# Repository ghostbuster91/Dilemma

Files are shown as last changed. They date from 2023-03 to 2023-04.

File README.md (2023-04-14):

This is a modified version of Dilemma keyboard 3x6_3 with more aggerssive pinky stagger.

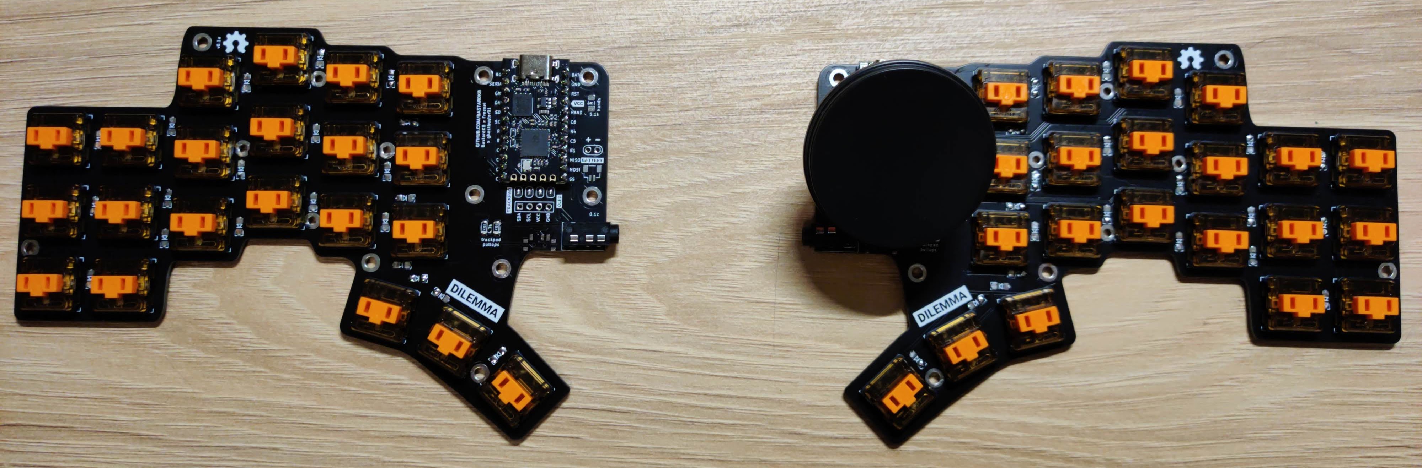
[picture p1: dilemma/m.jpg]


Head over [here](./dilemma/build_guide.md) for a build guide.

QMK firmaware: https://github.com/ghostbuster91/qmk_firmware/tree/bkb-master/keyboards/bastardkb/dilemma/3x6_3

<div align="center">




</div>

---

The Dilemma is a vertical stagger low-profile keyboard with mods.



## Table of contents

- [Features](#features)
- [Versions](#versions)
- [Wireless abilities](#wireless-abilities)
- [BOM](#bom)
  - [DIY version](#diy-version)
  - [Assembled version](#assembled-version)
  - [Trackpad mod](#trackpad-mod)
  - [Cases](#cases)
- [Community mods](#community-mods)
- [Build guide](#build-guide)
- [Forks](#forks)
- [Support me on patreon](#support-me-on-patreon)
- [Others / in progress](#others--in-progress)

---

## Features

- Heavy pinky stagger
- MX and choc compatible
- Reversible PCB
- Elite-pi / Splinky / Nice!Nano compatible
- Tenting puck footprint

## Versions

There are 2 versions of the dilemma, in 2 folders:

- `dilemma`, for DIY that requires an additional MCU (eg. kb2040)
- `dilemma_assembled`, for PCB assembly

The Dilemma is **made for rp2040**, so if you go with the DIY version you should source your MCU board accordingly.

## Wireless abilities

ZMK does not support input devices at the moment, and QMK does not support BLE.

However, as this is meant to be a portable keyboard, some ground work has been laid with the DIY version:

- pinout compatible with nice!nano
- 2 battery connectors footprints: JST, and THT
- on / off button footprint

At this time, the assembled version does not support wireless.

## BOM

The PCB can work on standalone.

Depending on which version you go with, you will need to source different items.

On top of the basic build, you can add a range of options, which require additional components:

- 3d printed case
- mods (eg. trackpad)

Both versions of the Dilemma require:

| Part name | Amount | Link / source |
| --- | --- | --- |
| Audio jack | 2 | |
| Button, 4x4x1.5 | 2 | |

### DIY version

On top of the parts mentioned above, you will need:

| Part name | Amount | Link / source |
| --- | --- | --- |
| SOD123 Diodes | 34 | Farnell, Mouser, Aliexpress |
| Dilemma PCB, DIY, 1.2mm | 2 | See Release section |
| RP2040 MCU board | 2 | KB2040, elite-pi... |
| Header pins | 2\*12  | |

Please note, **the Dilemma is compatible only with rp2040 boards !**

The release section contains the latest gerbers.

Order in 1.2mm thickness.

### Assembled version



On top of the parts mentioned above, you will need:

| Part name | Amount | Link / source |
| --- | --- | --- |
| Dilemma PCB, assembled, 1.2mm | 2 | See Release section |

The release section contains the latest gerbers with BOM and POS files.

Order in 1.2mm thickness.

### Trackpad mod



This is the first mod made for the keyboard - so it can function as a standalone input device.

It uses I2C on the DIY version, and SPI on the assembled version.

The DIY version requires removing 2 resistors from the trackpad (see build guide).

When installing the trackpad mod, you will need:

| Part name | Amount | Link / source |
| --- | --- | --- |
| M3 screw, torx, 6mm | 4 | Conrad |
| M3x5x5 screw insert | 4 | Aliexpress |
| Cirque trackpad\* | 1 | Mouser |
| 3d printed parts\*  | | See `mechanical` folder |

\*You can use either the 35mm (TM035035-2024-003) or 40mm (TM040040-2024-303).
Print the appropriate parts from the `mechanical` folder.

If building the PCBA version, you will also need:

| Part name | Amount | Link / source |
| --- | --- | --- |
| 12-position FPC cable, 0.5mm pitch, same side contacts, 100mm | 1 | Farnell |

If building the DIY version, you will also need:

| Part name | Amount | Link / source |
| --- | --- | --- |
| SOD123 Resistor, 5kOhms | 2 | |
| Cables | | |

### Cases

There are a range of cases available. See details in the `mechanical/cases` folder.



## Community mods

There are a range of community mods available (hex plates, covers...).

You can find more information in the readme in the `mechanical/community mods` folder.



## Build guide

https://docs.bastardkb.com/hc/en-us/sections/6848232395410-Dilemma

## Forks

- [3x6 version](https://github.com/bstiq/Dilemma_3x6/)
- [3x5 + 3 version](https://github.com/dixls/Dilemma-3mod)

## Support me on Patreon

If you like the keyboard, please consider helping me with Patreon: https://www.patreon.com/bastardkb

I post regular updates and hindsight on my work. I work full time on keyboard innovation, and this helps a lot !

## Others / in progress

The PCB has available connectors for:

- oled

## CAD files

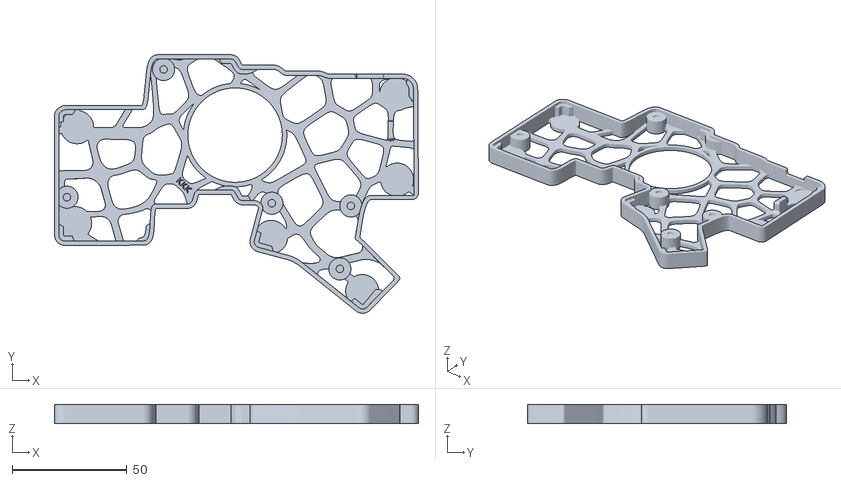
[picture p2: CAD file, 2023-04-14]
mechanical/cases/tenting_puck/tenting_puck_v3_26_mod.stl
158.9 x 112.9 x 8.40

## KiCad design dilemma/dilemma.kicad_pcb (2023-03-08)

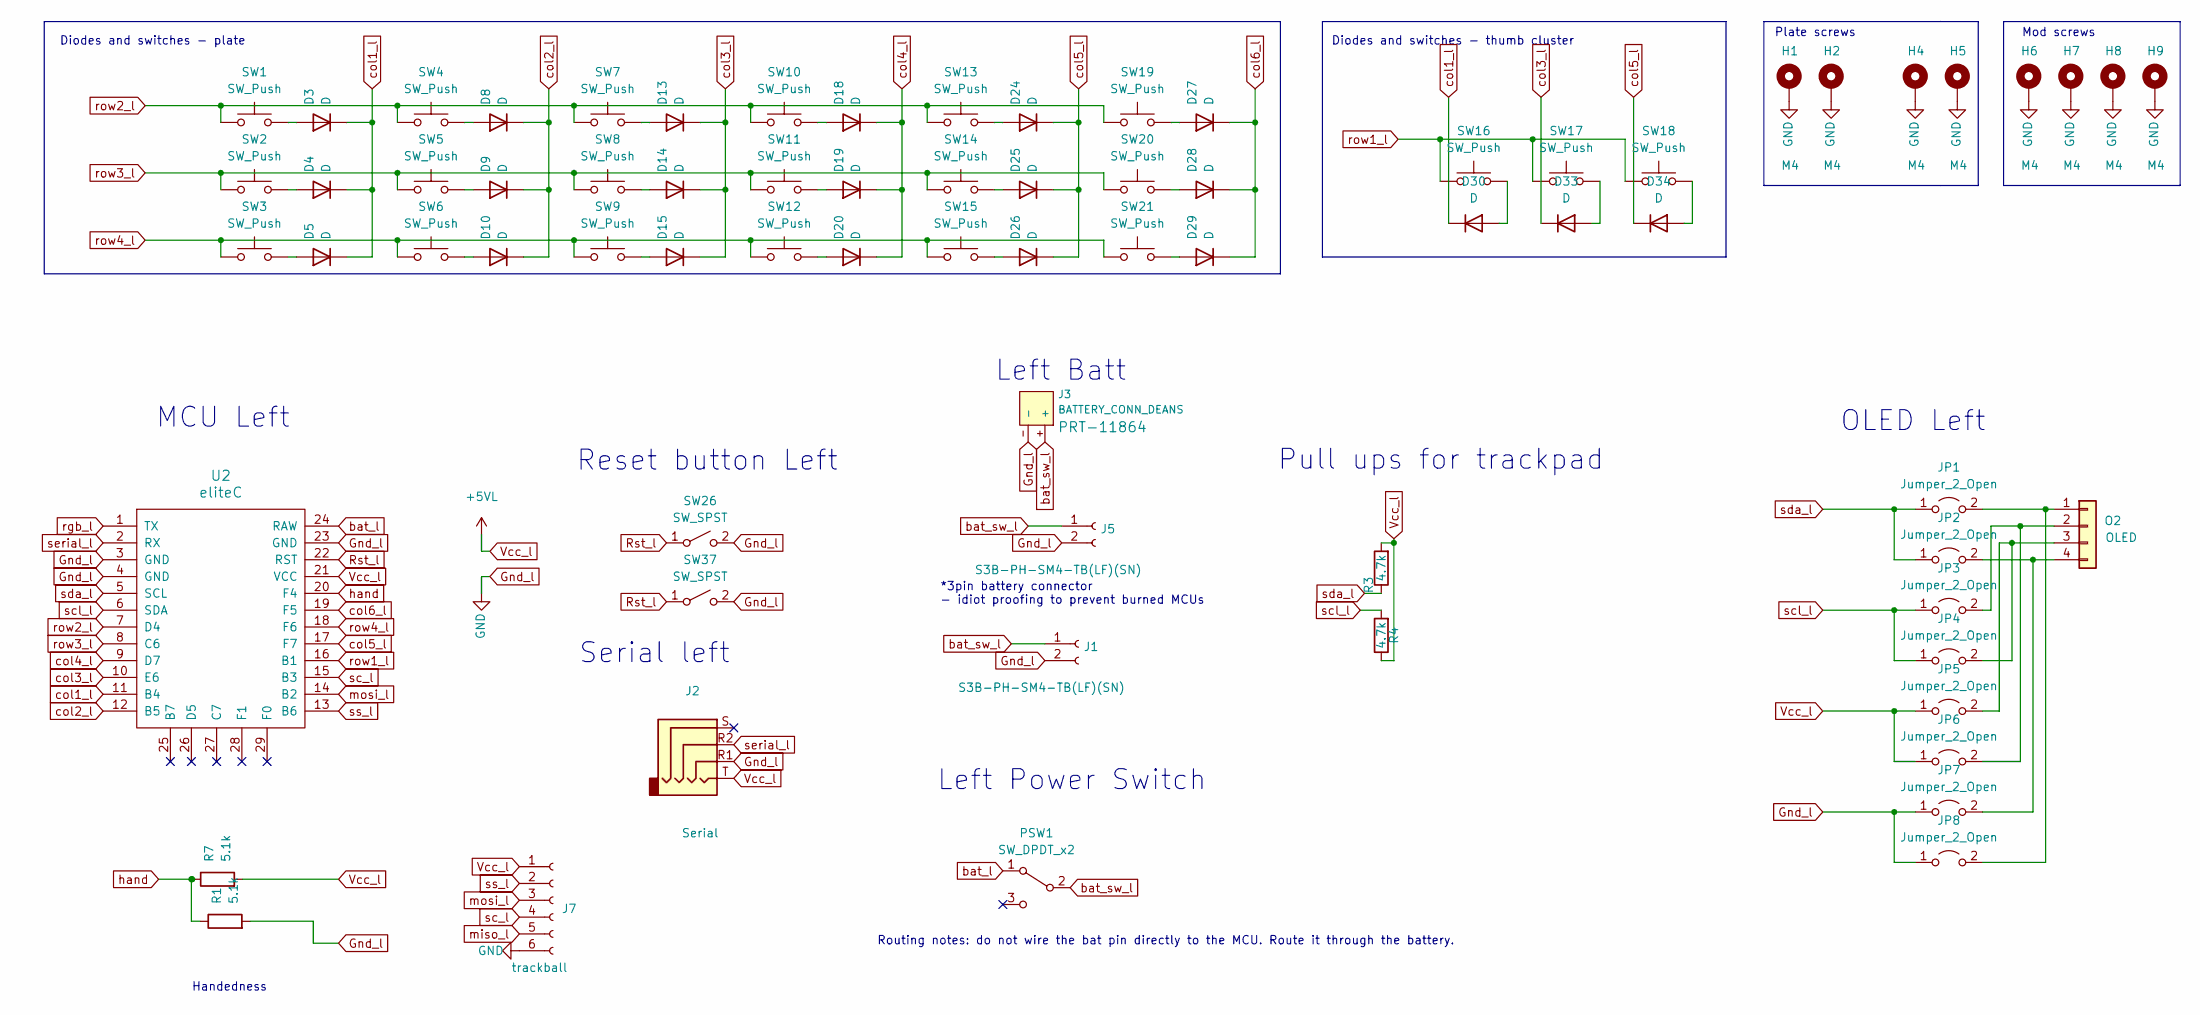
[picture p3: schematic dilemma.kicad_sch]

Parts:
D3, D4, D5, D8, D9, D10, D13, D14, D15, D18, D19, D20, D24, D25, D26, D27, D28, D29, D30, D33, D34: D; D_1206_handsolder_reversible
H1, H2, H4, H5, H6, H7, H8, H9: M4; MountingHole_3mm_Pad_thin
J1, J5: S3B-PH-SM4-TB(LF)(SN); JST_SH_BM02B-SRSS-TB_1x02-1MP_P1.00mm_Vertical; LCSC C265101
J2: Serial; Jack_3.5mm_PJ320E_Horizontal_reversible
J3: BATTERY_CONN_DEANS; battery_connector_THT
J7: trackball; 6_PinHeader
JP1, JP2, JP3, JP4, JP5, JP6, JP7, JP8: Jumper_2_Open; SolderJumper-2_P1.3mm_Open_RoundedPad1.0x1.5mm
O2: OLED; PinHeader_1x04_P2.54mm_Vertical
PSW1: SW_DPDT_x2; Switch_MSK-12C01-07; LCSC C431540
R1, R7: 5.1k; R_1206_handsolder; JLCPCB BOM 1
R3, R4: 4.7k; R_1206_handsolder_reversible; LCSC C269746
SW1, SW2, SW3, SW4, SW5, SW6, SW7, SW8, SW9, SW10, SW11, SW12, SW13, SW14, SW15, SW16, SW17, SW18, SW19, SW20, SW21: SW_Push; SW_MX_choc
SW26, SW37: SW_SPST; SW_Push_1P1T_NO_6x6mm_H9.5mm
U2: eliteC; pro-micro

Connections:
Gnd_l: H1.1, H2.1, H4.1, H5.1, H6.1, H7.1, H8.1, H9.1, J1.2, J2.R1, J3.-, J5.2, J7.6, JP7.1 (A), JP8.1 (A), R1.2, SW26.2 (B), SW37.2 (B), U2.3 (GND), U2.4 (GND), U2.23 (GND)
unnamed: D3.2 (A), SW1.2
unnamed: D4.2 (A), SW2.2
unnamed: D5.2 (A), SW3.2
unnamed: D8.2 (A), SW4.2
unnamed: D9.2 (A), SW5.2
unnamed: D10.2 (A), SW6.2
unnamed: D13.2 (A), SW7.2
unnamed: D14.2 (A), SW8.2
unnamed: D15.2 (A), SW9.2
unnamed: D18.2 (A), SW10.2
unnamed: D19.2 (A), SW11.2
unnamed: D20.2 (A), SW12.2
unnamed: D24.2 (A), SW13.2
unnamed: D25.2 (A), SW14.2
unnamed: D26.2 (A), SW15.2
unnamed: D30.2 (A), SW16.2
unnamed: D33.2 (A), SW17.2
unnamed: D34.2 (A), SW18.2
unnamed: JP1.2 (B), JP8.2 (B), O2.1
unnamed: JP2.2 (B), JP7.2 (B), O2.4
unnamed: JP3.2 (B), JP6.2 (B), O2.2
unnamed: JP4.2 (B), JP5.2 (B), O2.3
unnamed: D27.2 (A), SW19.2
unnamed: D28.2 (A), SW20.2
unnamed: D29.2 (A), SW21.2
Rst_l: SW26.1 (A), SW37.1 (A), U2.22 (RST)
Vcc_l: J2.T, J7.1, JP5.1 (A), JP6.1 (A), R3.2, R4.1, R7.2, U2.21 (VCC)
bat_l: PSW1.1 (A), U2.24 (RAW)
bat_sw_l: J1.1, J3.+, J5.1, PSW1.2 (B)
col1_l: D3.1 (K), D4.1 (K), D5.1 (K), D30.1 (K), U2.11 (B4)
col2_l: D8.1 (K), D9.1 (K), D10.1 (K), U2.12 (B5)
col3_l: D13.1 (K), D14.1 (K), D15.1 (K), D33.1 (K), U2.10 (E6)
col4_l: D18.1 (K), D19.1 (K), D20.1 (K), U2.9 (D7)
col5_l: D24.1 (K), D25.1 (K), D26.1 (K), D34.1 (K), U2.17 (F7)
col6_l: D27.1 (K), D28.1 (K), D29.1 (K), U2.19 (F5)
hand: R1.1, R7.1, U2.20 (F4)
mosi_l: J7.3, U2.14 (B2)
rgb_l: U2.1 (TX)
row1_l: SW16.1, SW17.1, SW18.1, U2.16 (B1)
row2_l: SW1.1, SW4.1, SW7.1, SW10.1, SW13.1, SW19.1, U2.7 (D4)
row3_l: SW2.1, SW5.1, SW8.1, SW11.1, SW14.1, SW20.1, U2.8 (C6)
row4_l: SW3.1, SW6.1, SW9.1, SW12.1, SW15.1, SW21.1, U2.18 (F6)
sc_l: J7.4, U2.15 (B3)
scl_l: JP3.1 (A), JP4.1 (A), R4.2, U2.6 (SDA)
sda_l: JP1.1 (A), JP2.1 (A), R3.1, U2.5 (SCL)
serial_l: J2.R2, U2.2 (RX)
ss_l: J7.2, U2.13 (B6)

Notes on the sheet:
MCU Left
Left Batt
Handedness
Plate screws
Routing notes: do not wire the bat pin directly to the MCU. Route it through the battery.
Serial left
Diodes and switches - plate
Reset button Left
Pull ups for trackpad
Mod screws
Left Power Switch
OLED Left
Diodes and switches - thumb cluster
*3pin battery connector - idiot proofing to prevent burned MCUs

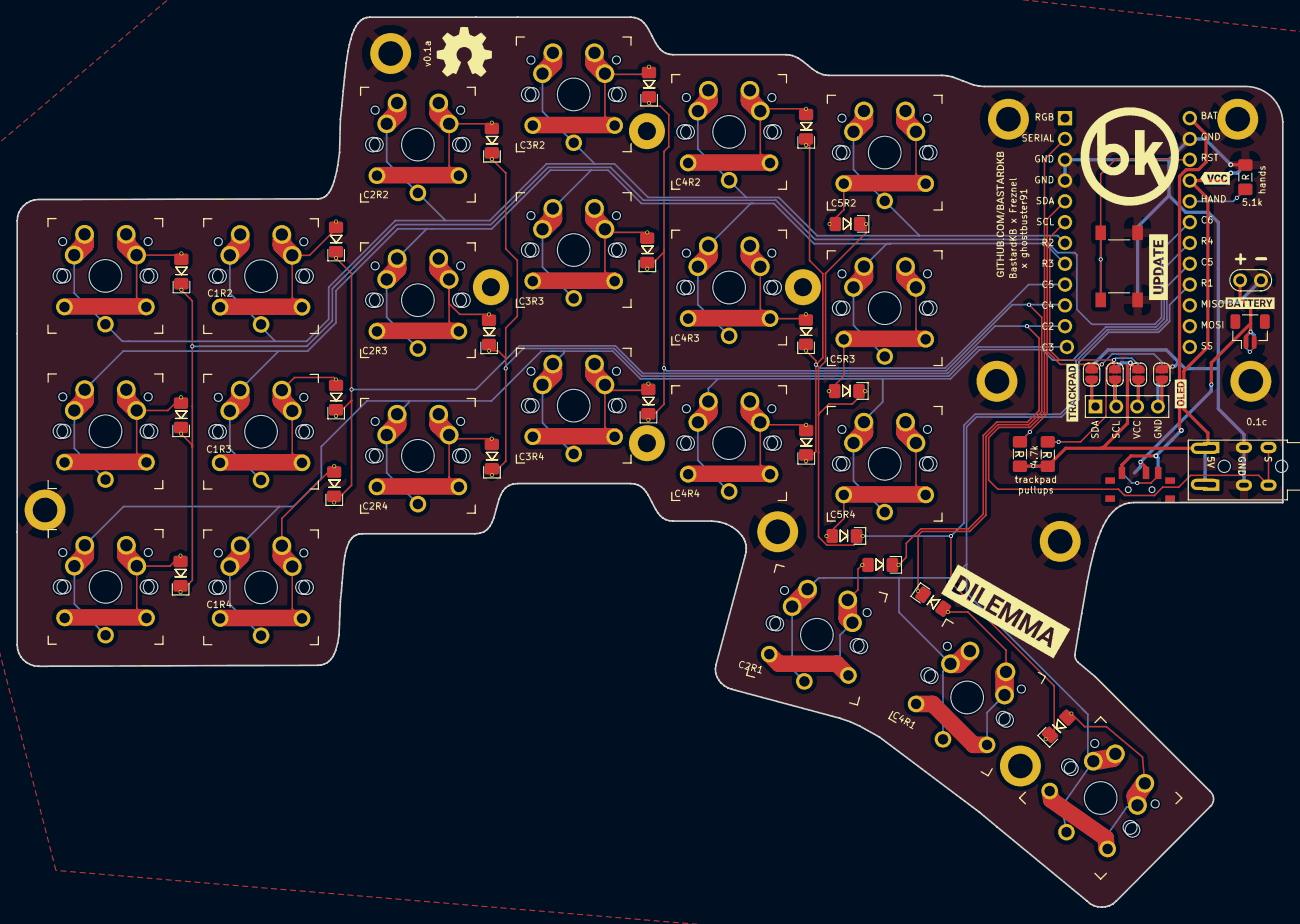
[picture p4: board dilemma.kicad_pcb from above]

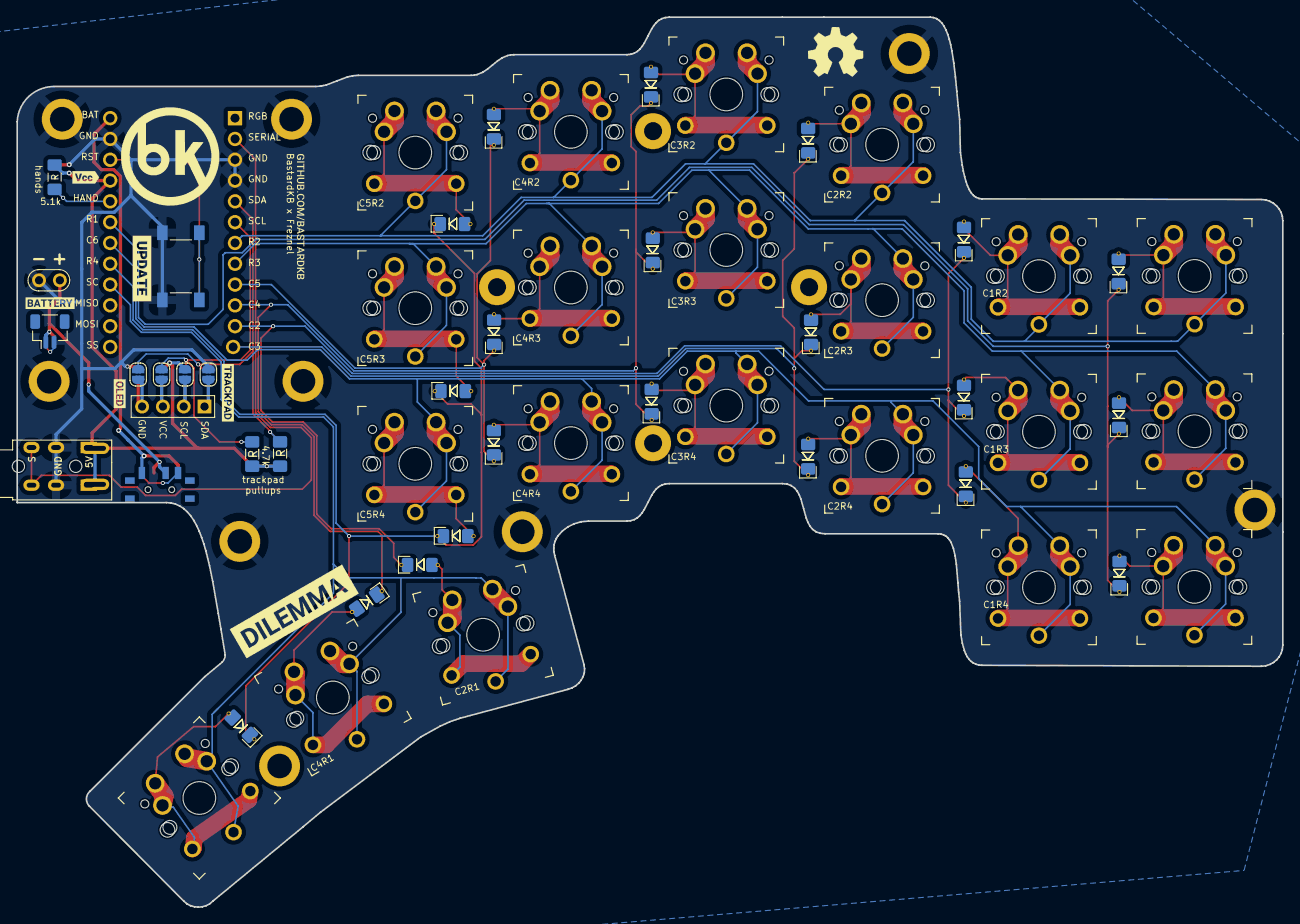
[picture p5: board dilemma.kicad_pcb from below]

Board: 2 copper layers, 154.5 x 108.7 mm, 85 parts (15 on the bottom side), 44 nets.

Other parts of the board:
kibuzzard-61F01A92, kibuzzard-61F01A92#2: G***; kibuzzard-61F01A92
kibuzzard-61F01C84, kibuzzard-61F01C84#2: G***; kibuzzard-61F01C84
kibuzzard-628D3AA1: G***; kibuzzard-628D3AA1
kibuzzard-628D396A: G***; kibuzzard-628D396A
kibuzzard-628DFB5F, kibuzzard-628DFB5F#2: G***; kibuzzard-628DFB5F
kibuzzard-628DFB48, kibuzzard-628DFB48#2: G***; kibuzzard-628DFB48
kibuzzard-628DFB95, kibuzzard-628DFB95#2: G***; kibuzzard-628DFB95
kibuzzard-628E0199, kibuzzard-628E0199#2: G***; kibuzzard-628E0199

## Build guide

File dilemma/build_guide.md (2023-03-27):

# Dilemma DIY build guide

This guide was done for a modified version of DIY Dilemma, however steps should be the same for the unmodified version as the modification changes only the amount of switches.

The Dilemma PCB is a reversible PCB meaning that both halves are the same but because the bottom part is mirrored part of the top part it is possible to use it for the other side.

The current PCB project is done in a way that if you put two halves in front of you then the "front" ("red") layer is on the left side and the "bottom" ("blue") layer is on the right.

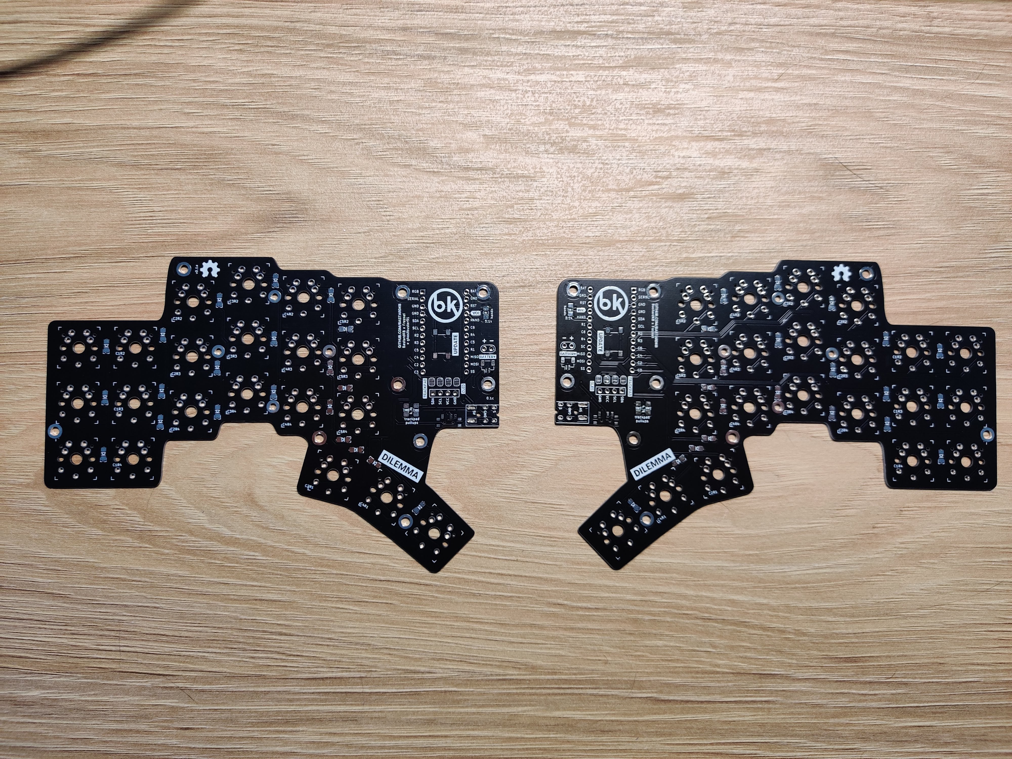
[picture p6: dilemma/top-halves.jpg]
top_halves


1. Soldering jumpers (optional)

This step is optional, do it only if you want to use OLED or I2C deviced on a particular side.

Jumpers have to be soldered on the "front" sides of both halves. That means that on the left side you will have to solder them on the top, and on the right side - on the bottom.

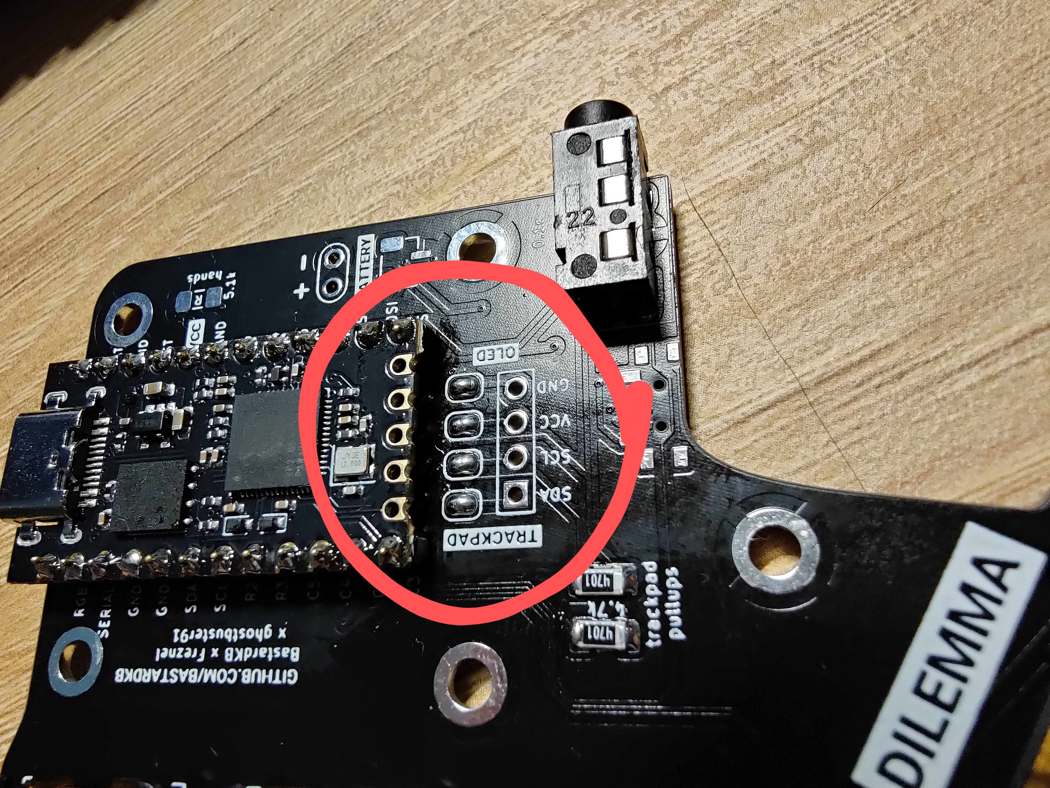
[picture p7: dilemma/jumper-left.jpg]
jumper_left

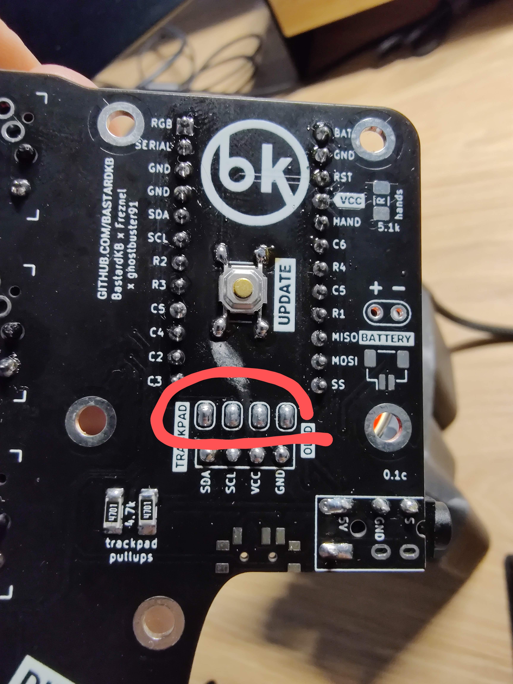
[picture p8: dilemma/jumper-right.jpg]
jumper_right


2. Install controller

_The Dilemma is only compatible with rp2040 boards._

To check if your controller is compatible refer to the following table: https://github.com/Bastardkb/technical-docs/wiki/RP2040-controllers

_Important_ Since one of the halves is flipped you will also have to flip one of yours controllers. Follow the legends both on the controller and the PCB to figuer out how to install it.
In my case the controller on the left had components facing up, and the one on the right side had components facing down.

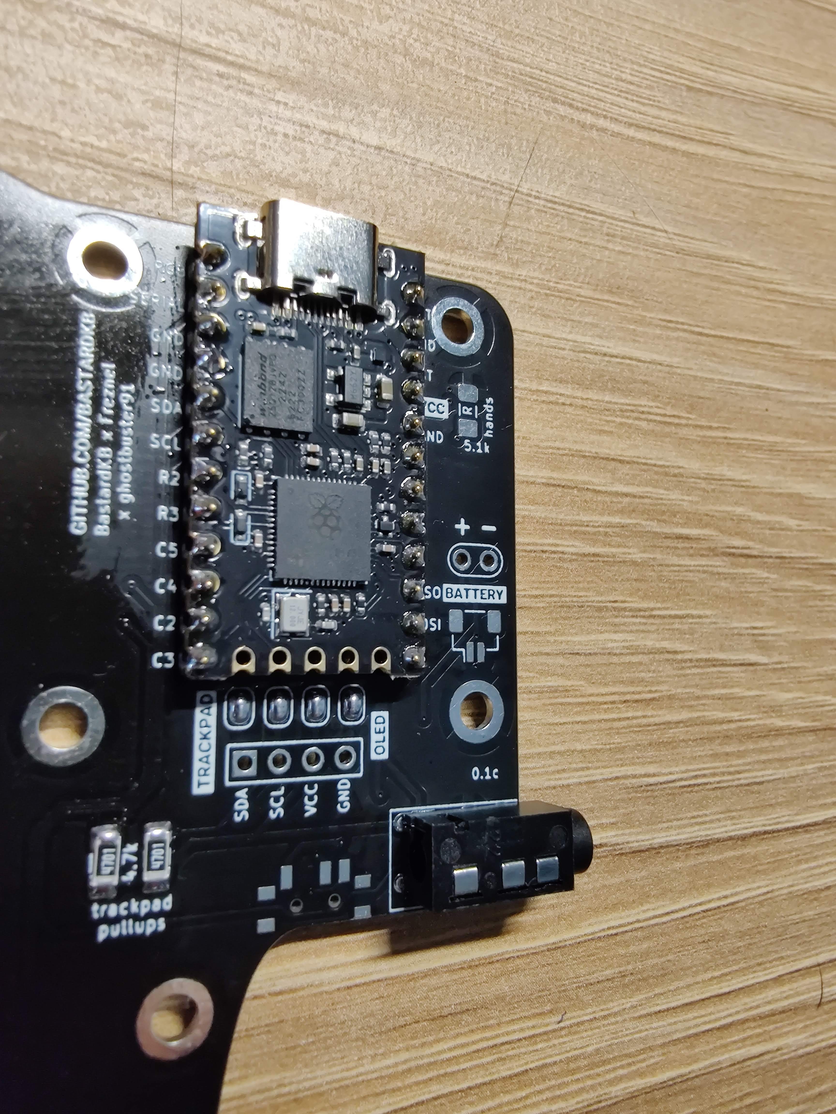
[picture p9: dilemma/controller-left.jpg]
controller-left

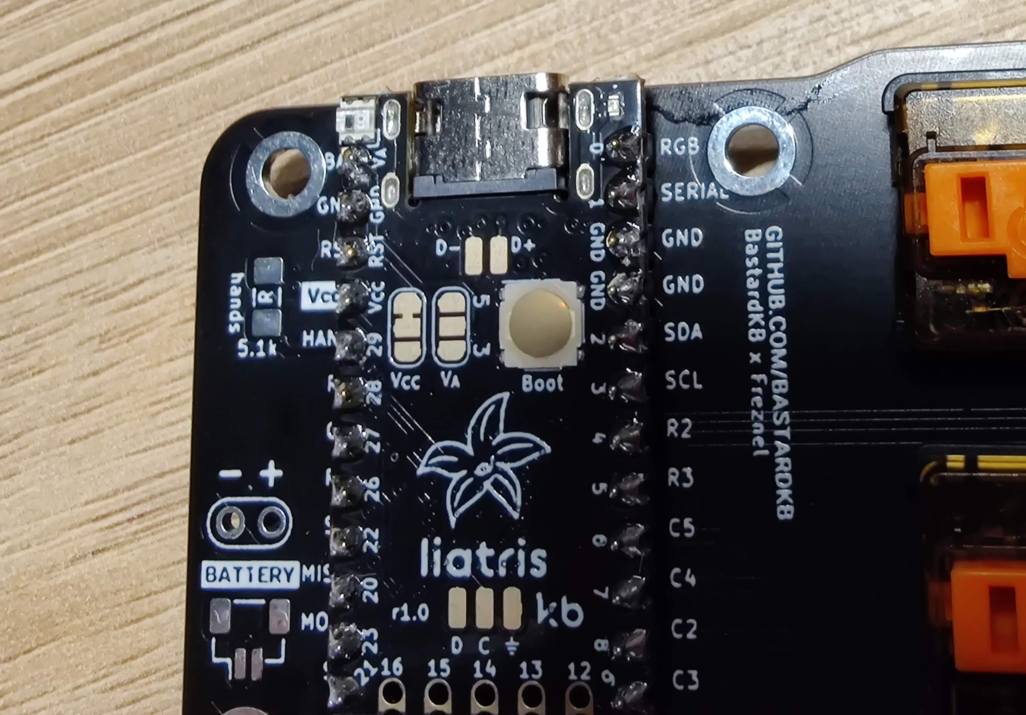
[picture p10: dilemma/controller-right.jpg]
controller-right


3. Install the audio jack

Nothing special here. As an additional note it can be soldered on the top as well as on the bottom.

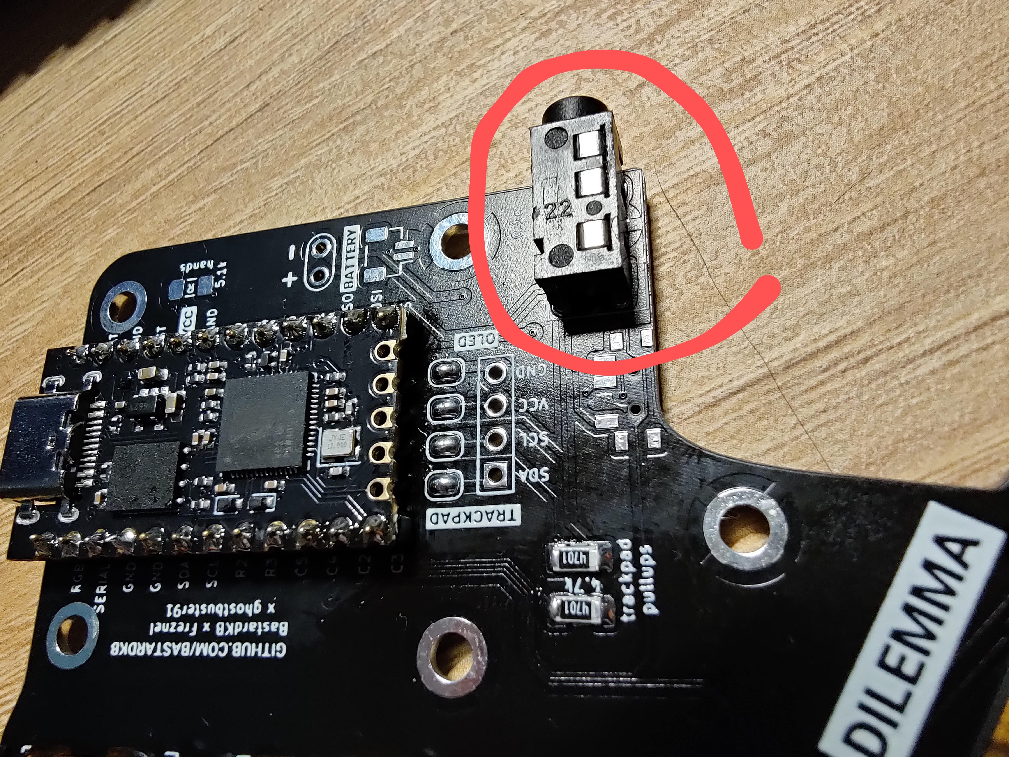
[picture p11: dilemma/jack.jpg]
jack


4. Install diodes

Again, nothing fancy. Can be soldered on either side. Pay attention to the orientation.

5. Install switches

Solder in your switches of preference.

6. Install reset button

Solder in reset buttons on the bottom of each half.

7. Enable handness (optional)

There is an optional feature called handness that allows keyboard to detect which side is master regardless of which one is connected to the PC.

https://github.com/Bastardkb/bastardkb-qmk/blob/dc3e11edcca343fe1a2ba550949bebeea407f8b9/keyboards/bastardkb/dilemma/3x5_2/splinky/config.h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

```c
// To use the handedness pin, resistors need to be installed on the PCB.
// If so, uncomment the following code, and undefine MASTER_RIGHT above.
//#define SPLIT_HAND_PIN GP29
// If you've soldered the handedness pull-up on the upper side instead of the
// left one, uncomment the following line.
//#define SPLIT_HAND_PIN_LOW_IS_LEFT // High -> right, Low -> left.
```

The idea is simple - one side pulls the pin high, and the other pulls the pin low.

For this to work "hand" resistors have to be installed on both sides on the same "side". Meaning that either both go on the top or one the bottom of the PCB.

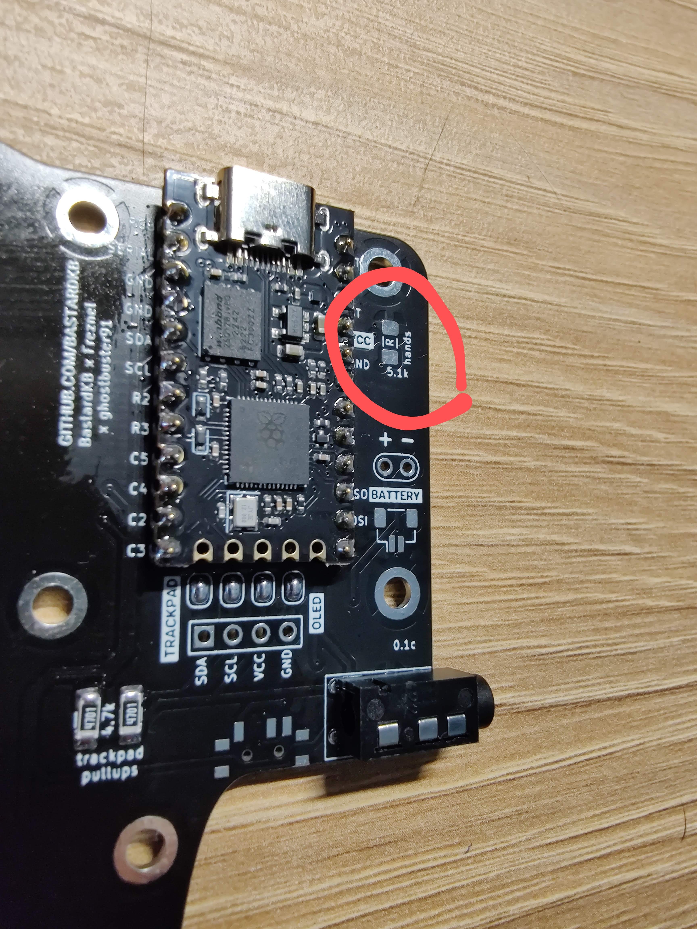
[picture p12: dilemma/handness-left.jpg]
handness-left

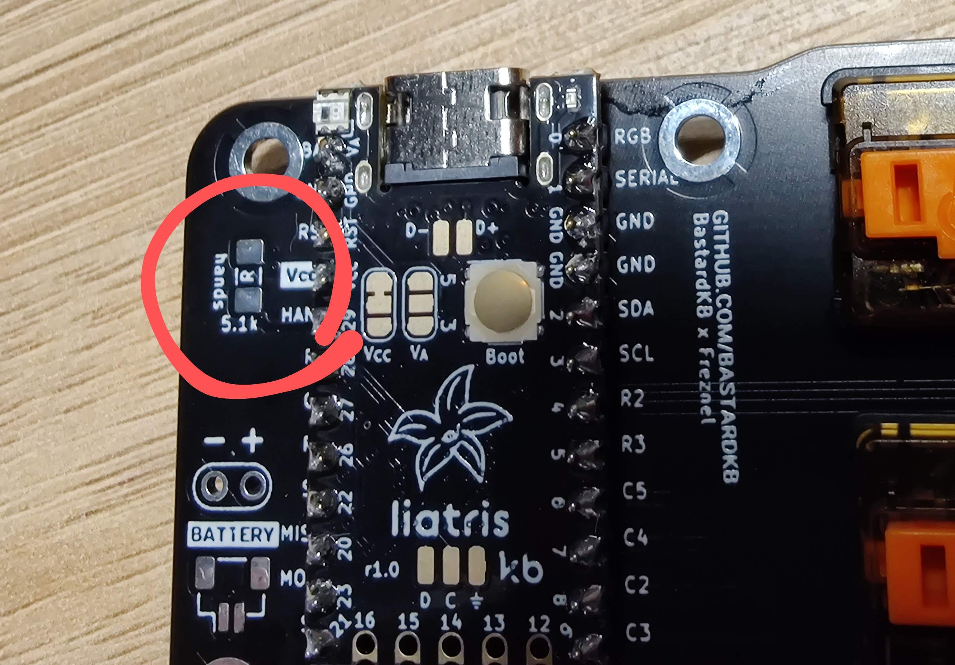
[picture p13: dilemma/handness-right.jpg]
handness-right


8. Install cirque trackpad (optional)

The are three resistors that are important for us: R1, R7 and R8. R1 controls whether the device works in I2C or SPI mode. For the DIY Dilemma we need it to work in I2C mode which means that we need to desolder R1.
R7 and R8 need to be desoldered if you are going to supply the device with 5V. If you are going to power it with 3V then its fine and you don't have to touch them. For more info refer to https://github.com/Keycapsss/cirque-trackpad

Cirque trackpad is connected with the board using 4 pins: GND, VCC, SCL(clock) and SDA(data). That means to you need to figure out what kind of voltage you have on VCC.
You can check it in the specification of your controller, or you can measure it directly on the pad.

After that you need to connect pads from the PCB with corresponding pads on the Cirque trackpad.

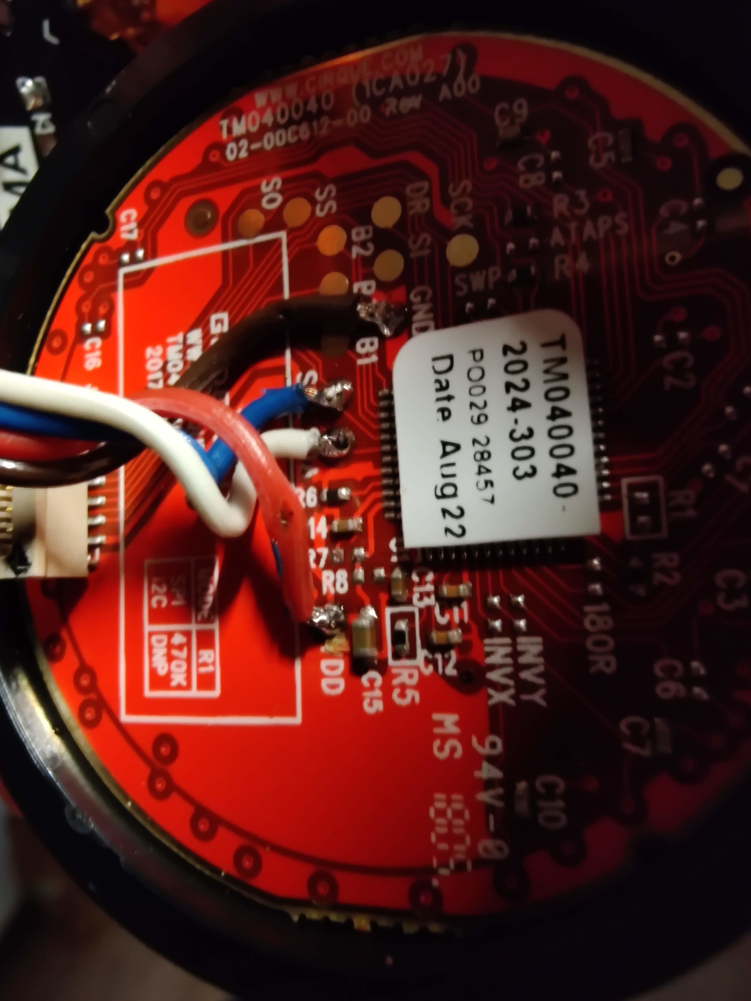
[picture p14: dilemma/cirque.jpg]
cirque

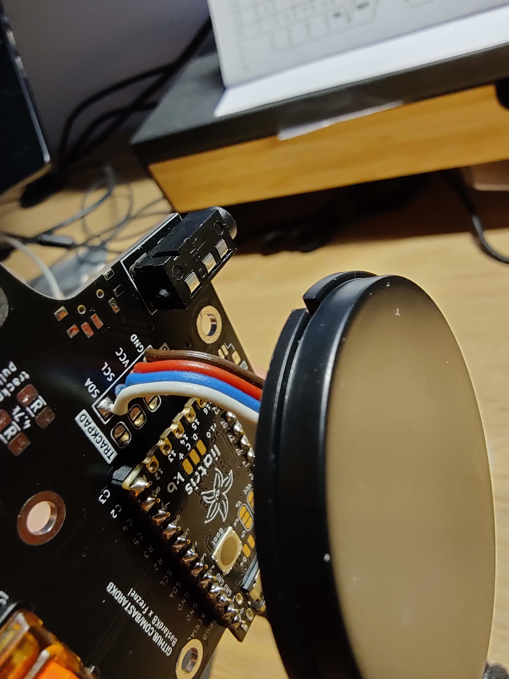
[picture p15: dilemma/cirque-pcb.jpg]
cirque_pcb


Special thanks to:

- Quentin Lebastard for the creation of Dilemma and many other awesome keyboards
- Arkadiusz Dobrowolski for figuring out jumpers and helping me with some desoldering
- Various people from bastardkb discord who were patiently answering my questions

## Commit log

2023-03-01 Add thumb key
    [dilemma.kicad_pcb, dilemma.kicad_sch]
2023-03-02 Create place for col6
    [dilemma.kicad_pcb, dilemma.kicad_sch]
2023-03-02 Add 6th column
    [dilemma.kicad_pcb, dilemma.kicad_sch]
2023-03-03 Fix drc errors
    [dilemma.kicad_pcb]
2023-03-03 Remove H4 hole
    [dilemma.kicad_pcb, dilemma.kicad_sch]
2023-03-08 Revert "Remove H4 hole"
    This reverts commit eafe3389c8530ed03ec8ad130b3a2f53ccdd09a2.
    [dilemma.kicad_pcb, dilemma.kicad_sch]
2023-03-08 Move mounting hole to the left
    [dilemma.kicad_pcb]
2023-03-08 Update slik screen layer
    [dilemma.kicad_pcb]
2023-03-08 Extend outline
    [dilemma.kicad_pcb]
2023-03-12 Add modified case for tenting_puck
    [tenting_puck_v3_26.stl, tenting_puck_v3_26_mod.stl]
2023-04-14 Update case
    [tenting_puck_v3_26_mod.stl]

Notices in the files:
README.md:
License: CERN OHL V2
